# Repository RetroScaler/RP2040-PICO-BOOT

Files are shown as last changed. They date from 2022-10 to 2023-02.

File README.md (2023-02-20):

# RP2040-PICO-BOOT
The RP2040 PICO BOOT allows you to build your own IPL replacement modchip，It is a modified version of the Raspberry Pi Pico.

## Features

- Includes all the functions of Raspberry Pi Pico
- Without any driver, you can burn the program through Type-C cable
- Add a 'Reset' button

## Pictures

3D Picture of PCBA

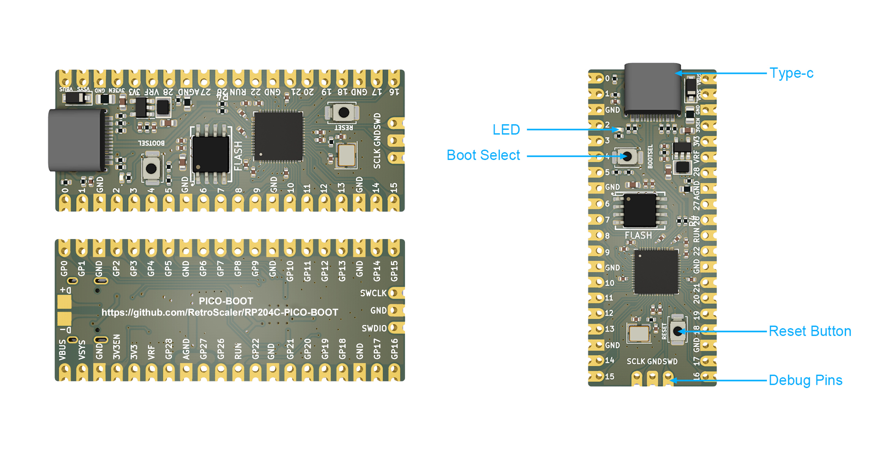
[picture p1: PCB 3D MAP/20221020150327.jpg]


The pinout 

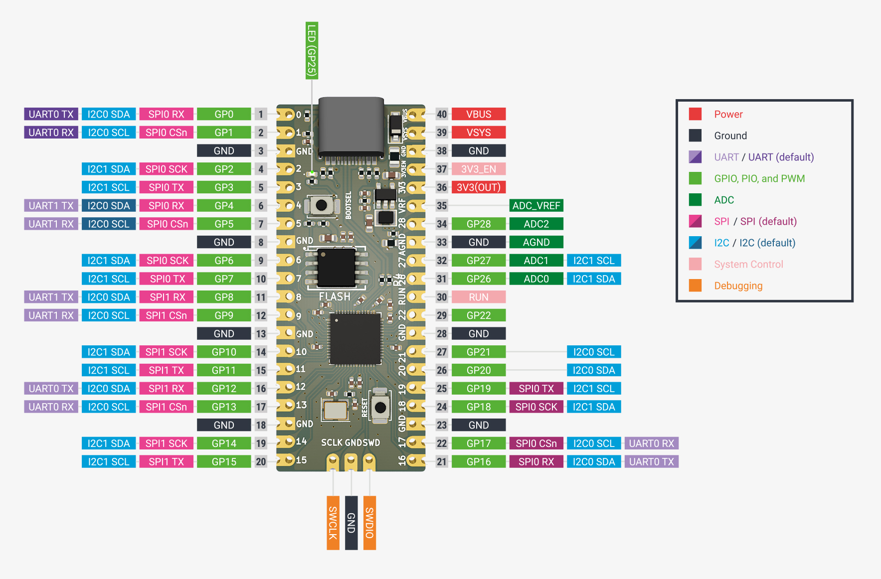
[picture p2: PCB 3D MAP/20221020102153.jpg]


## 🤝 Support

Contributions, issues, and feature requests are welcome!

if you like this project, stay tuned !

You can quickly purchase the finished product with this link：[Go to AliExpress shopping platform](https://www.aliexpress.us/item/3256804731684211.html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)

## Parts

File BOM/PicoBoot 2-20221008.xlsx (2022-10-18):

PicoBoot 2-20221008
序号 | 名称 | 标号 | 型号 | 封装 | 数量
SMT
1 | 贴片电容 | C2, C4, C19 | 22PF | C0402 | 3
2 | 贴片电容 | C5, C6, C7, C8, C11, C12, C13, C14, C15, C16, C18, C101 | 100NF | C0402 | 12
3 | 贴片电容 | C3, C10 | 1UF | C0402 | 2
4 | 贴片电容 | C1, C9, C17 | 10UF | C0603 | 3
5 | 贴片电阻 | R10 | 1R | 0402 | 1
6 | 贴片电阻 | R102 | 220R | 0402 | 1
7 | 贴片电阻 | GPIO25_RESISTOR1 | 470R | 0402 | 1
8 | 贴片电阻 | R1, R11 | 1K | 0402 | 2
9 | 贴片电阻 | R5, R6 | 5.1K | 0402 | 2
10 | 贴片电阻 | R101 | 5.6K | 0402 | 1
11 | 贴片电阻 | R2, R103 | 10K | 0402 | 2
12 | 贴片电阻 | R7 | 100k 1% | 0402 | 1
13 | 贴片电阻 | R12 | 150k 1% | 0402 | 1
14 | 贴片电阻 | R8 | 680k 1% | 0402 | 1
15 | 贴片电阻 | R3, R4 | 27R | 0402 | 2
16 | 贴片电阻 | R9 | 200R | 0603 | 1
17 | 贴片二极管 | D1 | 1N4002W | SOD-123 | 1
18 | 贴片电感 | L1 | 2.2UH | WPN252010UF2R2MT | 1
19 | 自恢复保险丝 |  | 6V/1A | Fuse_0805 | 1
20 | 芯片 | U3 | RP2040TR13 | RP2040-QFN-56 | 1
21 | 芯片 | U1 | TD6810-ADJ | SOT-23-5 | 1
22 | 芯片 | FLASH | W25Q16JVSSIQ | SOIC-8_5.23x5.23mm_P1.27mm | 1
23 | 无源晶振 | Y1 | 12MHZ | 3225-4Pin_3.2x2.5mm | 1
24 | 贴片灯 | D1 | 贴片普绿灯 | LED_0603 | 1
25 | 贴片开关 | J2, RSW1 | 2PIN立式贴片开关 | SW-2PIN-V-3X4X2MM | 2
26 | 贴片TYPE-C母座 | USB1 | 贴片TYPE-C母座 | TYPE-C-31-M-12 | 1
27 | 线路板 | PCB | PicoBoot 2-20221017 |  | 1

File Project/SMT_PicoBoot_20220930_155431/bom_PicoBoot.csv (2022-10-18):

Comment | Description | Designator | Footprint | LibRef | Pins | Quantity
 |  | ,, |  |  |  | 3
10uf 0603 | Capacitor SMD 0603 (1608 Metric), square (rectangular) end terminal, IPC_7351 nominal, (Body size source: http://www.tortai-tech.com/upload/download/2011102023233369053.pdf), generated with kicad-footprint-generator | C1,C9 | C_0603_1608Metric |  |  | 2
22pf 0402 | Capacitor SMD 0402 (1005 Metric), square (rectangular) end terminal, IPC_7351 nominal, (Body size source: IPC-SM-782 page 76, https://www.pcb-3d.com/wordpress/wp-content/uploads/ipc-sm-782a_amendment_1_and_2.pdf), generated with kicad-footprint-generator | C2,C19 | C_0402_1005Metric |  |  | 2
1uf 0402 | Capacitor SMD 0402 (1005 Metric), square (rectangular) end terminal, IPC_7351 nominal, (Body size source: IPC-SM-782 page 76, https://www.pcb-3d.com/wordpress/wp-content/uploads/ipc-sm-782a_amendment_1_and_2.pdf), generated with kicad-footprint-generator | C3,C10 | C_0402_1005Metric |  |  | 2
22pF | Capacitor SMD 0402 (1005 Metric), square (rectangular) end terminal, IPC_7351 nominal, (Body size source: IPC-SM-782 page 76, https://www.pcb-3d.com/wordpress/wp-content/uploads/ipc-sm-782a_amendment_1_and_2.pdf), generated with kicad-footprint-generator | C4 | C_0402_1005Metric |  |  | 1
100nf 0402 | Capacitor SMD 0402 (1005 Metric), square (rectangular) end terminal, IPC_7351 nominal, (Body size source: IPC-SM-782 page 76, https://www.pcb-3d.com/wordpress/wp-content/uploads/ipc-sm-782a_amendment_1_and_2.pdf), generated with kicad-footprint-generator | C6,C7,C11,C13,C14,C8,C5,C16,C18,C15,C12 | C_0402_1005Metric |  |  | 11
10uf 0402 | Capacitor SMD 0603 (1608 Metric), square (rectangular) end terminal, IPC_7351 nominal, (Body size source: IPC-SM-782 page 76, https://www.pcb-3d.com/wordpress/wp-content/uploads/ipc-sm-782a_amendment_1_and_2.pdf), generated with kicad-footprint-generator | C17 | C_0603_1608Metric |  |  | 1
0.1uf 0402 | Capacitor SMD 0402 (1005 Metric), square (rectangular) end terminal, IPC_7351 nominal, (Body size source: IPC-SM-782 page 76, https://www.pcb-3d.com/wordpress/wp-content/uploads/ipc-sm-782a_amendment_1_and_2.pdf), generated with kicad-footprint-generator | C101 | C_0402_1005Metric |  |  | 1
1N4002W | SOD-123 | D1 | D_SOD-123 |  |  | 1
0805L050WR | Fuse SMD 0805 (2012 Metric), square (rectangular) end terminal, IPC_7351 nominal, (Body size source: https://docs.google.com/spreadsheets/d/1BsfQQcO9C6DZCsRaXUlFlo91Tg2WpOkGARC1WS5S8t0/edit?usp=sharing), generated with kicad-footprint-generator | F1 | Fuse_0805_2012Metric |  |  | 1
W25Q16JVUXIQ | SOIC, 8 Pin (http://www.winbond.com/resource-files/w25q32jv%20revg%2003272018%20plus.pdf#page=68), generated with kicad-footprint-generator ipc_gullwing_generator.py | FLASH | SOIC-8_5.23x5.23mm_P1.27mm |  |  | 1
LED_0402 | LED SMD 0402 (1005 Metric), square (rectangular) end terminal, IPC_7351 nominal, (Body size source: http://www.tortai-tech.com/upload/download/2011102023233369053.pdf), generated with kicad-footprint-generator | GPIO25_LED1 | LED_0402_1005Metric |  |  | 1
470 0402 | Resistor SMD 0402 (1005 Metric), square (rectangular) end terminal, IPC_7351 nominal, (Body size source: IPC-SM-782 page 72, https://www.pcb-3d.com/wordpress/wp-content/uploads/ipc-sm-782a_amendment_1_and_2.pdf), generated with kicad-footprint-generator | GPIO25_RESISTOR1 | R_0402_1005Metric |  |  | 1
MountingHole | Mounting Hole 2.1mm, no annular | H4,H3,H1,H2 | MountingHole_2.1mm |  |  | 4
TSA343G00-250J2 | http://www.alps.com/prod/info/E/HTML/Tact/SurfaceMount/SKRK/SKRKAHE020.html | J2,RSW1 | SW_Push_SPST_NO_Alps_SKRK |  |  | 2
2.54mm header 01x20 | Through hole straight pin header, 1x20, 2.54mm pitch, single row | J4,J3 | PinHeader_1x20_P2.54mm_Vertical |  |  | 2
Conn_01x03_Male | Through hole straight pin header, 1x03, 2.54mm pitch, single row | J5 | PinHeader_1x03_P2.54mm_Vertical |  |  | 1
2.2uH |  | L1 | WPN252010UF2R2MT |  |  | 1
NetTie_2 | Net tie, 2 pin, 0.5mm square SMD pads | NT1 | NetTie-2_SMD_Pad0.5mm |  |  | 1
1K 0402 | Resistor SMD 0402 (1005 Metric), square (rectangular) end terminal, IPC_7351 nominal, (Body size source: IPC-SM-782 page 72, https://www.pcb-3d.com/wordpress/wp-content/uploads/ipc-sm-782a_amendment_1_and_2.pdf), generated with kicad-footprint-generator | R1,R11 | R_0402_1005Metric |  |  | 2
10K 0402 | Resistor SMD 0402 (1005 Metric), square (rectangular) end terminal, IPC_7351 nominal, (Body size source: IPC-SM-782 page 72, https://www.pcb-3d.com/wordpress/wp-content/uploads/ipc-sm-782a_amendment_1_and_2.pdf), generated with kicad-footprint-generator | R2,R103 | R_0402_1005Metric |  |  | 2
27r 0402 resistor | Resistor SMD 0402 (1005 Metric), square (rectangular) end terminal, IPC_7351 nominal, (Body size source: IPC-SM-782 page 72, https://www.pcb-3d.com/wordpress/wp-content/uploads/ipc-sm-782a_amendment_1_and_2.pdf), generated with kicad-footprint-generator | R4,R3 | R_0402_1005Metric |  |  | 2
5.1K 0402 | Resistor SMD 0402 (1005 Metric), square (rectangular) end terminal, IPC_7351 nominal, (Body size source: IPC-SM-782 page 72, https://www.pcb-3d.com/wordpress/wp-content/uploads/ipc-sm-782a_amendment_1_and_2.pdf), generated with kicad-footprint-generator | R5,R6 | R_0402_1005Metric |  |  | 2
100K 0402 | Resistor SMD 0402 (1005 Metric), square (rectangular) end terminal, IPC_7351 nominal, (Body size source: IPC-SM-782 page 72, https://www.pcb-3d.com/wordpress/wp-content/uploads/ipc-sm-782a_amendment_1_and_2.pdf), generated with kicad-footprint-generator | R7 | R_0402_1005Metric |  |  | 1
680K | Resistor SMD 0402 (1005 Metric), square (rectangular) end terminal, IPC_7351 nominal, (Body size source: http://www.tortai-tech.com/upload/download/2011102023233369053.pdf), generated with kicad-footprint-generator | R8 | R_0402_1005Metric |  |  | 1
200 0603 | Resistor SMD 0603 (1608 Metric), square (rectangular) end terminal, IPC_7351 nominal, (Body size source: IPC-SM-782 page 72, https://www.pcb-3d.com/wordpress/wp-content/uploads/ipc-sm-782a_amendment_1_and_2.pdf), generated with kicad-footprint-generator | R9 | R_0603_1608Metric |  |  | 1
1 0402 | Resistor SMD 0402 (1005 Metric), square (rectangular) end terminal, IPC_7351 nominal, (Body size source: IPC-SM-782 page 72, https://www.pcb-3d.com/wordpress/wp-content/uploads/ipc-sm-782a_amendment_1_and_2.pdf), generated with kicad-footprint-generator | R10 | R_0402_1005Metric |  |  | 1
150K | Resistor SMD 0402 (1005 Metric), square (rectangular) end terminal, IPC_7351 nominal, (Body size source: http://www.tortai-tech.com/upload/download/2011102023233369053.pdf), generated with kicad-footprint-generator | R12 | R_0402_1005Metric |  |  | 1
5.6K 0402 | Resistor SMD 0402 (1005 Metric), square (rectangular) end terminal, IPC_7351 nominal, (Body size source: IPC-SM-782 page 72, https://www.pcb-3d.com/wordpress/wp-content/uploads/ipc-sm-782a_amendment_1_and_2.pdf), generated with kicad-footprint-generator | R101 | R_0402_1005Metric |  |  | 1
220 0402 | Resistor SMD 0402 (1005 Metric), square (rectangular) end terminal, IPC_7351 nominal, (Body size source: IPC-SM-782 page 72, https://www.pcb-3d.com/wordpress/wp-content/uploads/ipc-sm-782a_amendment_1_and_2.pdf), generated with kicad-footprint-generator | R102 | R_0402_1005Metric |  |  | 1
SON127P800X600X80-9N |  | REF** | SON127P800X600X80-9N |  |  | 1
TestPoint | SMD pad as test Point, diameter 1.0mm | TP1,TP2 | CustomTestPoint |  |  | 2
TD6810-ADJ | 5-pin SOT23 package | U1 | SOT-23-5 |  |  | 1
RP2040 | QFN, 56 Pin (http://www.cypress.com/file/416486/download#page=40), generated with kicad-footprint-generator ipc_dfn_qfn_generator.py | U3 | RP2040-QFN-56 |  |  | 1
TYPE-C-31-M-12 |  | USB1 | HRO-TYPE-C-31-M-12 |  |  | 1
3225_4P | SMD Crystal SERIES SMD3225/4 http://www.txccrystal.com/images/pdf/7m-accuracy.pdf, 3.2x2.5mm^2 package | Y1 | Crystal_SMD_3225-4Pin_3.2x2.5mm |  |  | 1

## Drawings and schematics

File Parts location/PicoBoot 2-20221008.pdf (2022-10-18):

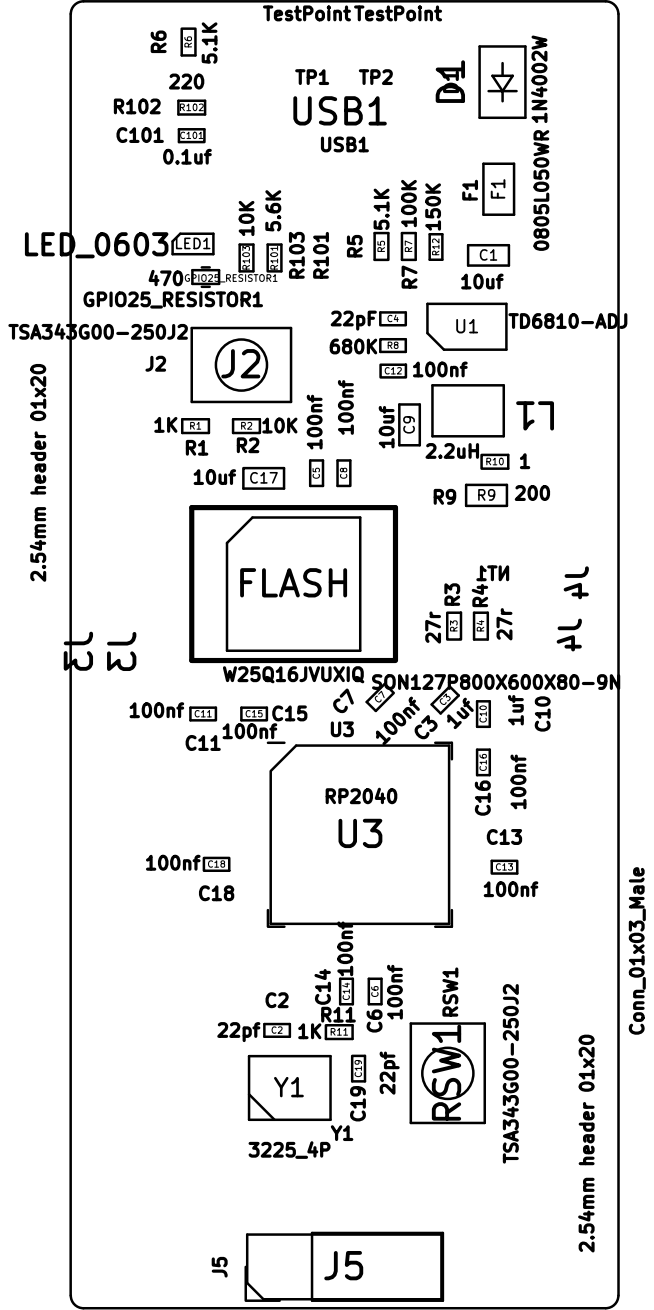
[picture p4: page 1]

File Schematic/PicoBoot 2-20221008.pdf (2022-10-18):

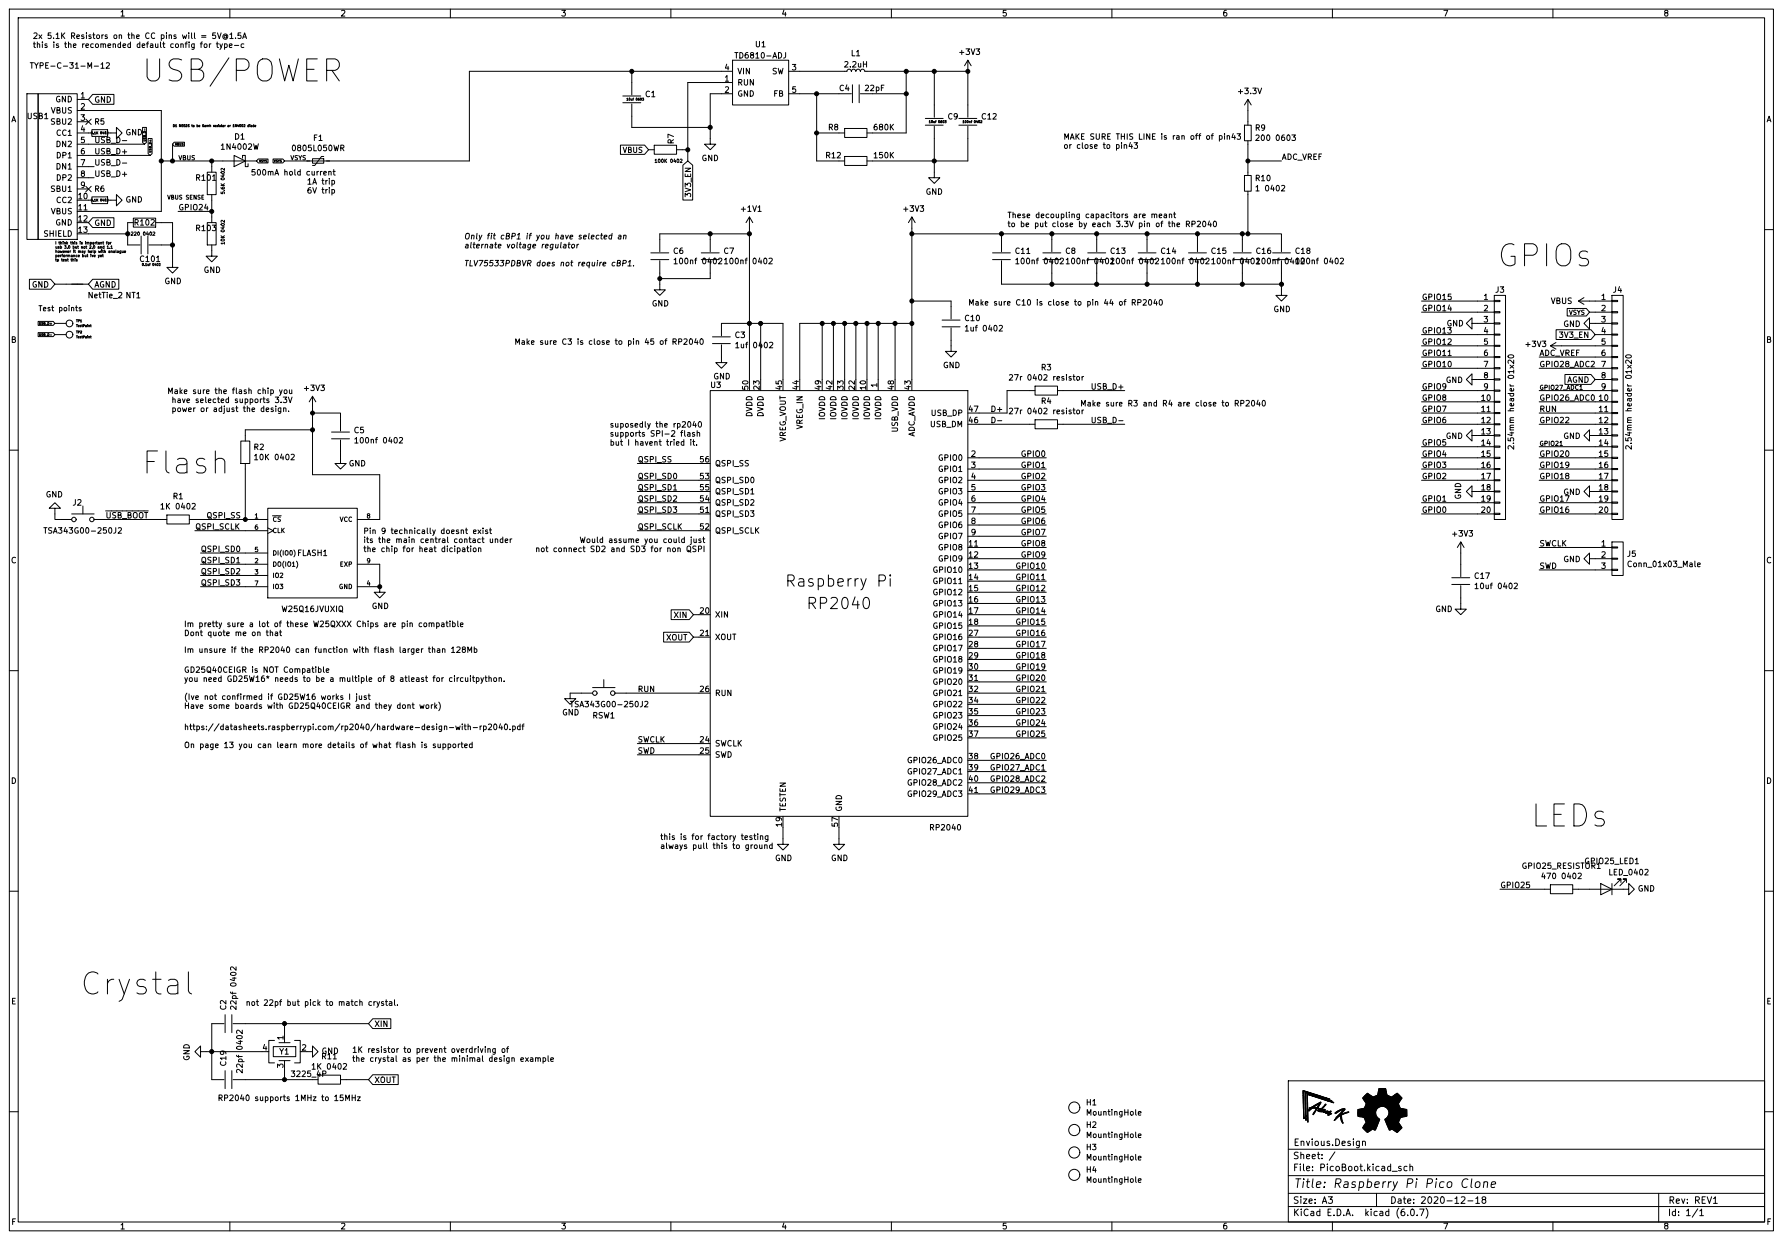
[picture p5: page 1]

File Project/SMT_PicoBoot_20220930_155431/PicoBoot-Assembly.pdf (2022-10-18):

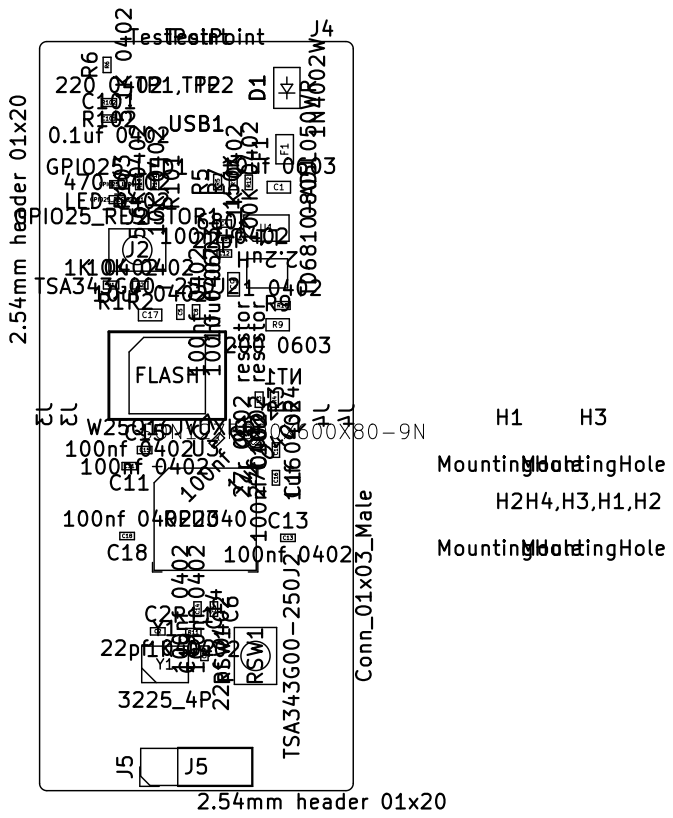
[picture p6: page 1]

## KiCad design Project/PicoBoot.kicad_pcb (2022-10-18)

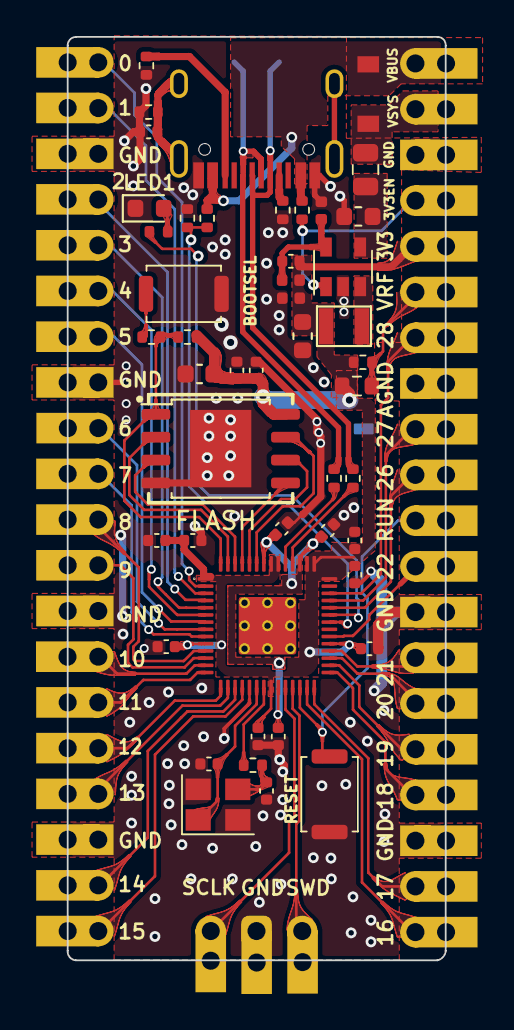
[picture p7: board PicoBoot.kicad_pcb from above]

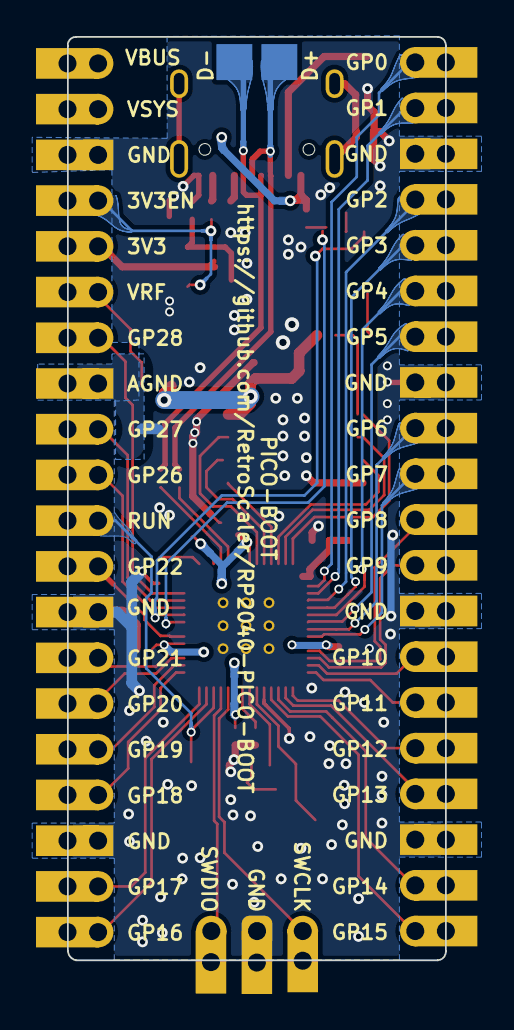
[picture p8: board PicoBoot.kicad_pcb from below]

Board: 2 copper layers, 21.0 x 51.3 mm, 53 parts (5 on the bottom side), 60 nets.

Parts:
C1, C9, C17: 10uf; C_0603_1608Metric
C2, C19: 22pf; C_0402_1005Metric
C3, C10: 1uf; C_0402_1005Metric
C4: 22pF; C_0402_1005Metric
C5, C6, C7, C8, C11, C12, C13, C14, C15, C16, C18: 100nf; C_0402_1005Metric
C101: 0.1uf; C_0402_1005Metric
D1: 1N4002W; D_SOD-123
F1: 0805L050WR; Fuse_0805_2012Metric
FLASH: W25Q16JVUXIQ; SOIC-8_5.23x5.23mm_P1.27mm
GPIO25_RESISTOR1: 470; R_0402_1005Metric
J2: TSA343G00-250J2; SW_Push_SPST_NO_Alps_SKRK
J3, J4: 2.54mm header 01x20; PinHeader_1x20_P2.54mm_Vertical
J5: Conn_01x03_Male; PinHeader_1x03_P2.54mm_Vertical
L1: 2.2uH; WPN252010UF2R2MT
LED1: LED_0603; LED_0603_1608Metric
NT1: NetTie_2; NetTie-2_SMD_Pad0.5mm
R1, R11: 1K; R_0402_1005Metric
R2, R103: 10K; R_0402_1005Metric
R3, R4: 27r; R_0402_1005Metric
R5, R6: 5.1K; R_0402_1005Metric
R7: 100K; R_0402_1005Metric
R8: 680K; R_0402_1005Metric
R9: 200; R_0603_1608Metric
R10: 1; R_0402_1005Metric
R12: 150K; R_0402_1005Metric
R101: 5.6K; R_0402_1005Metric
R102: 220; R_0402_1005Metric
RSW1: TSA343G00-250J2; SW_Push_SPST_NO_Alps_SKRK
TP1, TP2: TestPoint; CustomTestPoint
U1: TD6810-ADJ; SOT-23-5
U3: RP2040; RP2040-QFN-56
USB1: TYPE-C-31-M-12; HRO-TYPE-C-31-M-12
Y1: 3225_4P; Crystal_SMD_3225-4Pin_3.2x2.5mm

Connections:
3V3_EN: J4.4, R7.1, U1.1 (RUN)
+1V1: C3.1, C6.1, C7.1, U3.23 (DVDD), U3.45 (VREG_VOUT), U3.50 (DVDD)
+3V3: C4.2, C5.1, C8.1, C9.1, C10.1, C11.1, C12.1, C13.1, C14.1, C15.1, C16.1, C17.1, C18.1, FLASH.8 (VCC), J4.5, L1.2, R2.1, R8.1, R9.1, R10.2, U3.1 (IOVDD), U3.10 (IOVDD), U3.22 (IOVDD), U3.33 (IOVDD), U3.42 (IOVDD), U3.43 (ADC_AVDD), U3.44 (VREG_IN), U3.48 (USB_VDD), U3.49 (IOVDD)
/ADC_VREF: J4.6, R9.2, R10.1
/D+: R3.2, U3.47 (USB_DP)
/D-: R4.2, U3.46 (USB_DM)
/GPIO0: J3.20, U3.2 (GPIO0)
/GPIO1: J3.19, U3.3 (GPIO1)
/GPIO2: J3.17, U3.4 (GPIO2)
/GPIO3: J3.16, U3.5 (GPIO3)
/GPIO4: J3.15, U3.6 (GPIO4)
/GPIO5: J3.14, U3.7 (GPIO5)
/GPIO6: J3.12, U3.8 (GPIO6)
/GPIO7: J3.11, U3.9 (GPIO7)
/GPIO8: J3.10, U3.11 (GPIO8)
/GPIO9: J3.9, U3.12 (GPIO9)
/GPIO10: J3.7, U3.13 (GPIO10)
/GPIO11: J3.6, U3.14 (GPIO11)
/GPIO12: J3.5, U3.15 (GPIO12)
/GPIO13: J3.4, U3.16 (GPIO13)
/GPIO14: J3.2, U3.17 (GPIO14)
/GPIO15: J3.1, U3.18 (GPIO15)
/GPIO16: J4.20, U3.27 (GPIO16)
/GPIO17: J4.19, U3.28 (GPIO17)
/GPIO18: J4.17, U3.29 (GPIO18)
/GPIO19: J4.16, U3.30 (GPIO19)
/GPIO20: J4.15, U3.31 (GPIO20)
/GPIO21: J4.14, U3.32 (GPIO21)
/GPIO22: J4.12, U3.34 (GPIO22)
/GPIO24: R101.2, R103.1, U3.36 (GPIO24)
/GPIO25: GPIO25_RESISTOR1.2, U3.37 (GPIO25)
/GPIO26_ADC0: J4.10, U3.38 (GPIO26_ADC0)
/GPIO27_ADC1: J4.9, U3.39 (GPIO27_ADC1)
/GPIO28_ADC2: J4.7, U3.40 (GPIO28_ADC2)
/QSPI_SCLK: FLASH.6 (CLK), U3.52 (QSPI_SCLK)
/QSPI_SD0: FLASH.5 (DI(IO0)), U3.53 (QSPI_SD0)
/QSPI_SD1: FLASH.2 (DO(IO1)), U3.55 (QSPI_SD1)
/QSPI_SD2: FLASH.3 (IO2), U3.54 (QSPI_SD2)
/QSPI_SD3: FLASH.7 (IO3), U3.51 (QSPI_SD3)
/QSPI_SS: FLASH.1 (~CS), R1.1, R2.2, U3.56 (QSPI_SS)
/RUN: J4.11, RSW1.2, U3.26 (RUN)
/SWCLK: J5.1, U3.24 (SWCLK)
/SWD: J5.3, U3.25 (SWD)
/~USB_BOOT: J2.1, R1.2
AGND: J4.8, NT1.2
GND: C1.2, C2.1, C3.2, C5.2, C6.2, C7.2, C8.2, C9.2, C10.2, C11.2, C12.2, C13.2, C14.2, C15.2, C16.2, C17.2, C18.2, C19.1, C101.1, FLASH.4 (GND), J2.2, J3.3, J3.8, J3.13, J3.18, J4.3, J4.13, J4.18, J5.2, LED1.1 (K), NT1.1, R5.1, R6.1, R12.1, R102.2, R103.2, RSW1.1, U1.2 (GND), U3.19 (TESTEN), U3.57 (GND), USB1.1 (GND), USB1.12 (GND), Y1.2, Y1.4
unnamed: C1.1, F1.1, U1.4 (VIN)
unnamed: C4.1, R8.2, R12.2, U1.5 (FB)
unnamed: C19.2, R11.2, Y1.3
unnamed: C101.2, R102.1, USB1.13 (SHIELD)
unnamed: GPIO25_RESISTOR1.1, LED1.2 (A)
unnamed: L1.1, U1.3 (SW)
unnamed: R5.2, USB1.4 (CC1)
unnamed: R6.2, USB1.10 (CC2)
USB_D+: R3.1, TP1.1, USB1.6 (DP1), USB1.8 (DP2)
USB_D-: R4.1, TP2.1, USB1.5 (DN2), USB1.7 (DN1)
VBUS: D1.2 (A), J4.1, R7.2, R101.1, USB1.2 (VBUS), USB1.11 (VBUS)
VSYS: D1.1 (K), F1.2, J4.2
XIN: C2.2, U3.20 (XIN), Y1.1
XOUT: R11.1, U3.21 (XOUT)
